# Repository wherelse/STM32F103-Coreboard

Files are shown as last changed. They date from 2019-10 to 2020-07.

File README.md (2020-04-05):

# STM32F103-Coreboard

STM32测试核心板，设计用于硬件程序调试

### 硬件设计
芯片采用STM32F103C8T6，一个1.3inch OLED屏，六个用户按键，一个有源蜂鸣器，使用TP4056充电的1000mah充电电池，TYPE-C充电/数据端口。引出14个GPIO端口和一组SWD调试端口。

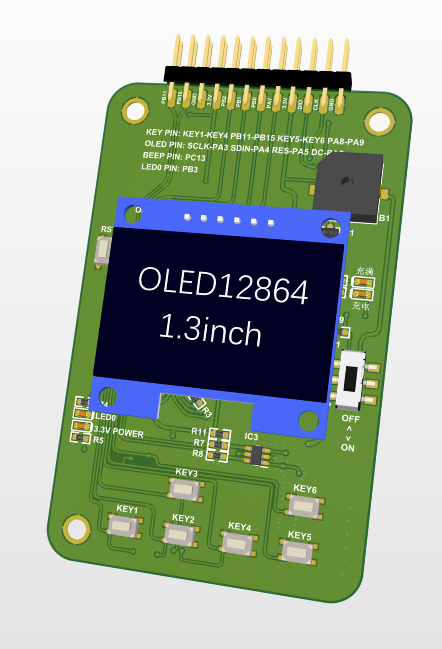
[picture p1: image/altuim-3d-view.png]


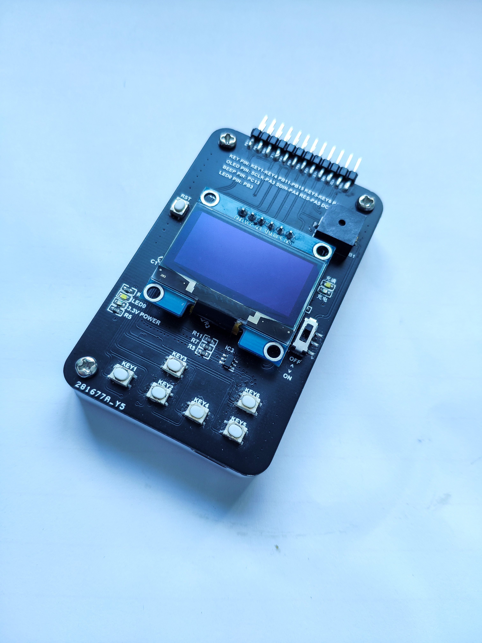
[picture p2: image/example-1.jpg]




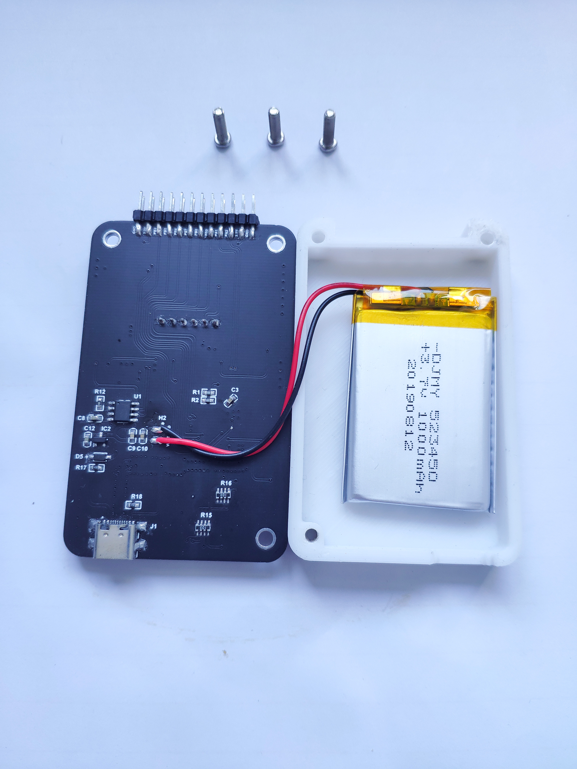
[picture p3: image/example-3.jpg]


PinMap：

| PB11 | PB10 | GND  | 3.3V | PB3  | PB1  | PB0  | PA7  | 3.3V | DIO  | CLK  | GND  |
| :--: | :--: | :--: | :--: | :--: | :--: | :--: | :--: | :--: | :--: | :--: | :--: |
| GND  | 3.3V | PB4  | PB5  | PB6  | PB7  | PB8  | PB9  | PA1  | PA2  | 3.3V | GND  |

TYPE-C端口可程序配置为虚拟串口、USB-HID等，用于数据传输。

使用PA0端口作为内置电池的电压采样输入端口，采样分压为1/2，用于指示电压状态。

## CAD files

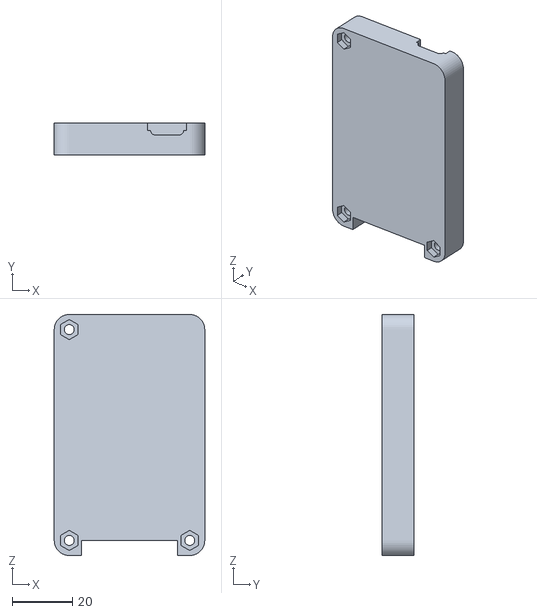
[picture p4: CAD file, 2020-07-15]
hardware/底壳.STL
50.0 x 10.5 x 80.0

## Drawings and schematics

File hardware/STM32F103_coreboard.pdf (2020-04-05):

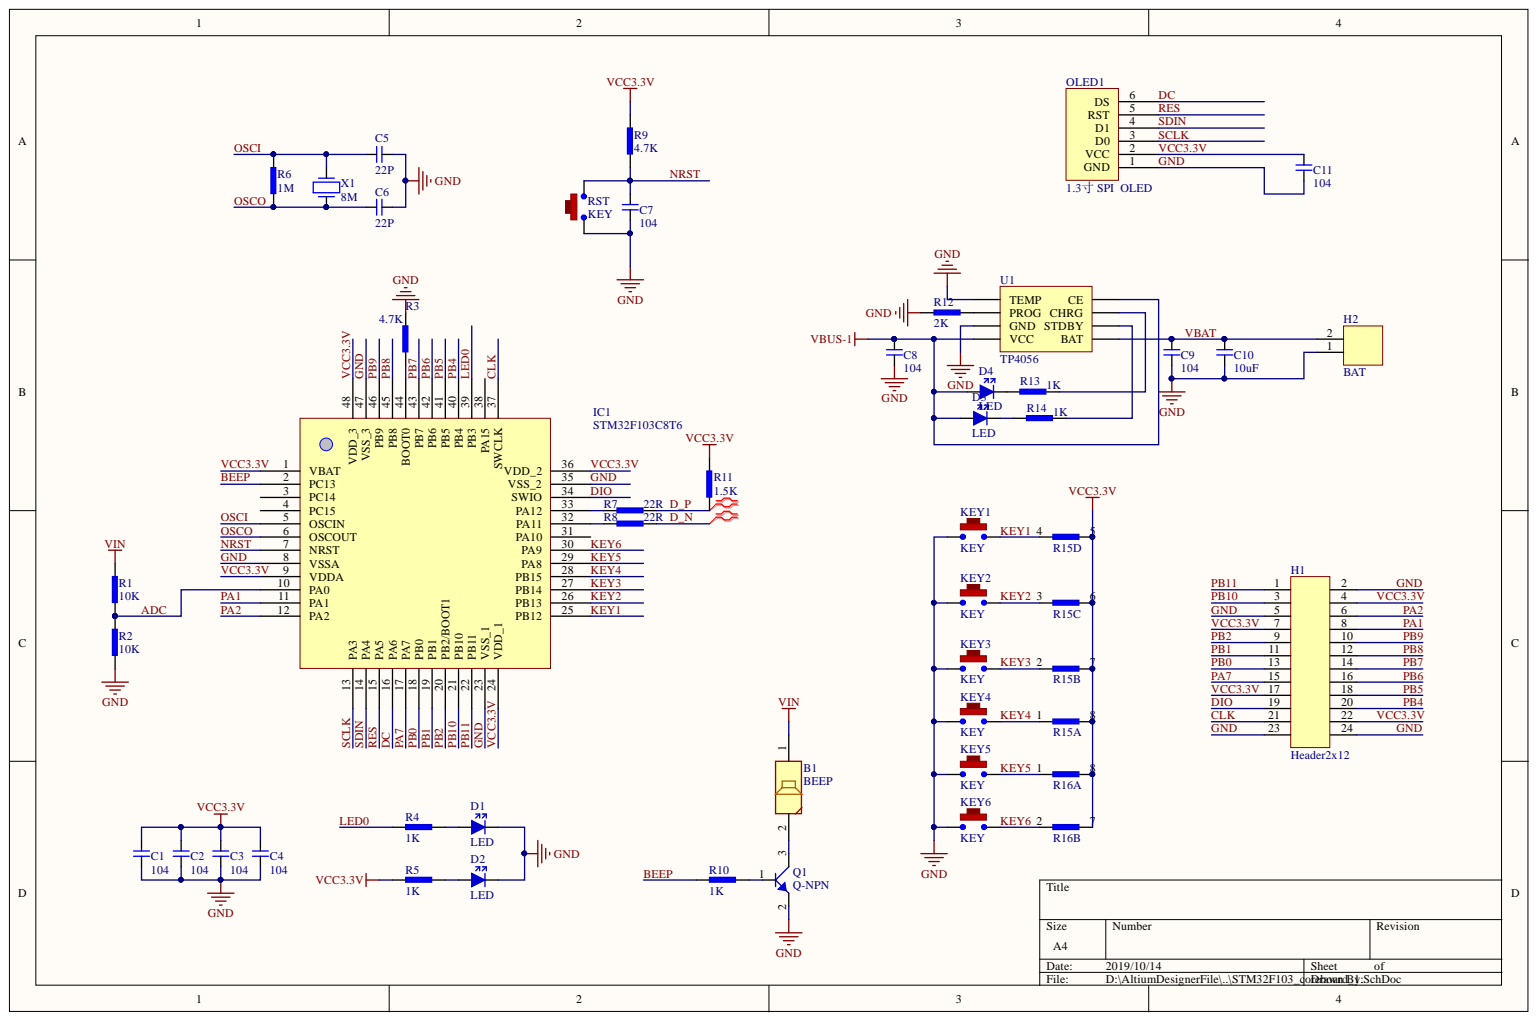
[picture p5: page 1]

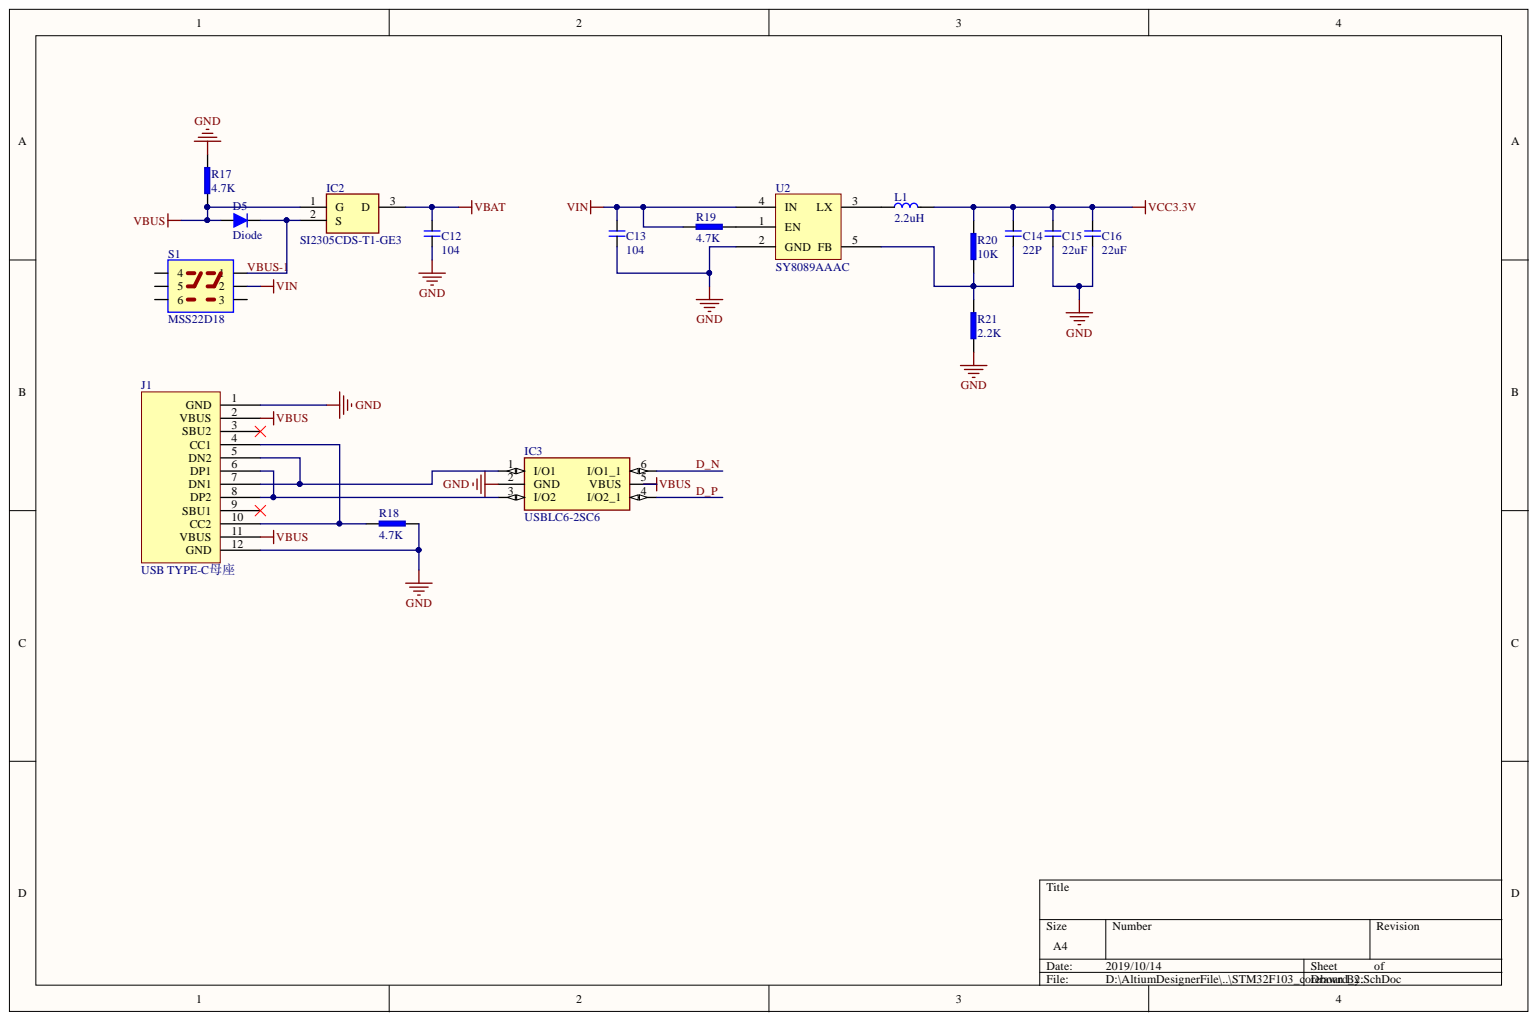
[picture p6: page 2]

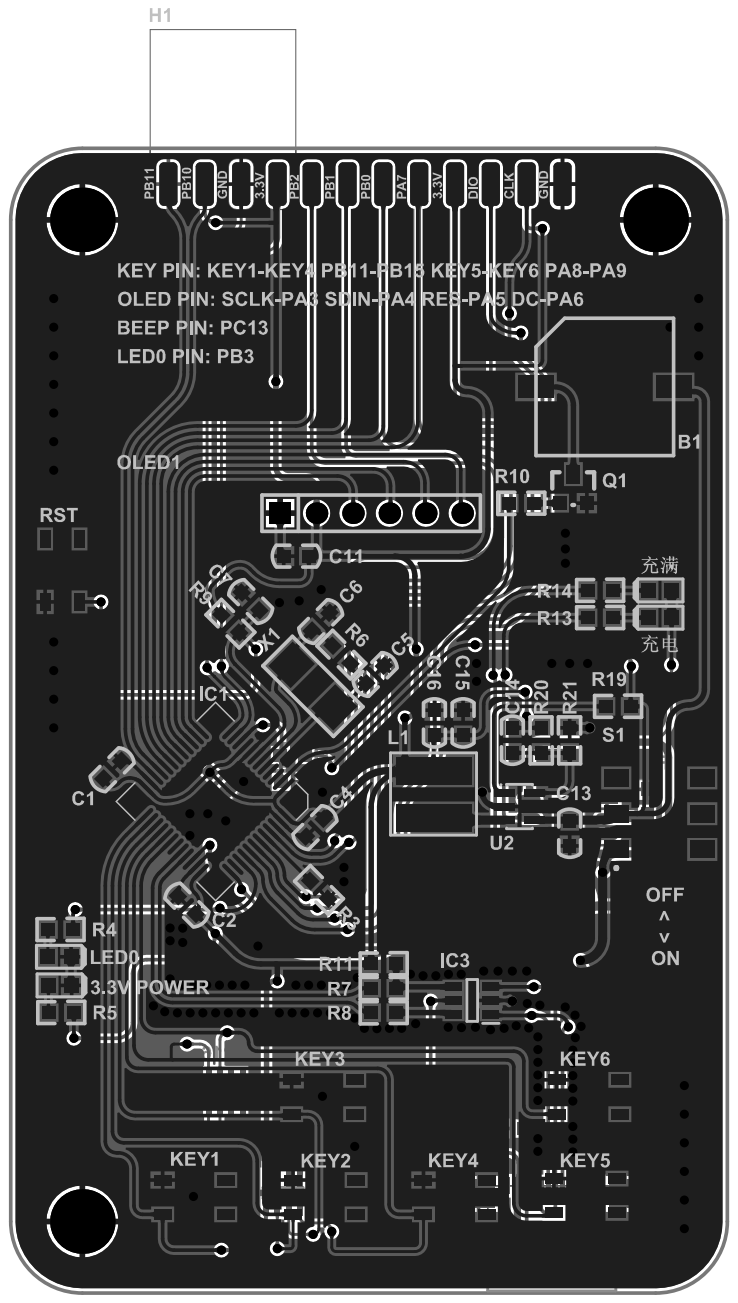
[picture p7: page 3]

Comment | Description | Designator | Footprint | LibRef | Quantity
BEEP | | B1 | MLT-9650 | BEEP | 1
104 | Cap | C1, C2, C3, C4, C7, C8C0603 | | CAP | 10
22P | Cap | C5,C6,C14 | C0603 | CAP | 3
10uF | Cap | C10 | C0603 | CAP | 1
22uF | Cap | C15,C16 | C0603 | CAP | 2
LED | | D1, D2, D3, D4 | LED0603 | LED | 4
Diode | | D5 | SOD123 | Diode | 1
Header2x12 | | H1 | HDR2X12_2.54_180HHeader2x12 | | 1
BAT | | H2 | BATIN | Header1x2 | 1
STM32F103C8T6 | | IC1 | LQFP48 | STM32F103C8T6 | 1
SI2305CDS-T1-GE3 | Integrated Circuit | IC2 | SOT95P237X112-3N | SI2305CDS-T1-GE3 | 1
USBLC6-2SC6 | Integrated Circuit | IC3 | SOT95P280X145-6N | USBLC6-2SC6 | 1
USBTYPE-C母座 | | J1 | USB-TYPEC-SMT | USBTYPE-C | 1
KEY | | KEY1, KEY2, KEY3, KEKEY3 X4X2.5 | | KEY | 7
2.2uH | | L1 | L-CDR5*5 | Inductance | 1
1.3寸 SPI OLED | 1.3寸 SPI OLED 128xOLE D1 | | OLED1.3INCH | 1.3寸 SPI OLED | 1
Q-NPN | | Q1 | SOT-23 | Q-NPN | 1
10K | | R1, R2, R20 | R0603 | RES | 3
4.7K | | R3, R9, R17, R18, R19R0603 | | RES | 5
1K | | R4, R5, R10, R13, R14R0603 | | RES | 5
1M | | R6 | R0603 | RES | 1
22R | | R7,R8 | R0603 | RES | 2
1.5K | | R11 | R0603 | RES | 1
2K | | R12 | R0603 | RES | 1
ResPack-4R | 排阻 | R15,R16 | 8P4R-0603 | ResPack-4R | 2
2.2K | | R21 | R0603 | RES | 1
MSS22D18 | | S1 | SWITCH-MSS22D18 | SWITCH-MSS22D18 | 1
TP4056 | | U1 | SOP8 | TP4056 | 1
SY8089AAAC | | U2 | SOT-23-5 | SY8089AAAC | 1
8M | | X1 | XTAL-5032 | XTAL | 1

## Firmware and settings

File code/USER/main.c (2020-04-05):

#include "includeFile.h"

/*------->定义FLASH相关变量和参数<----------------*/
//要写入到STM32 FLASH的参数数组
float Parameter_Buffer[8] = {0};                  //缓存数组
#define SIZE sizeof(Parameter_Buffer)             //数组长度
#define FLASH_SAVE_ADDR 0X08000000 + (100 * 1024) //STM32F103CBT6 FLASH 空间为128K 将数据存储在100K-128K的区域，\
设置FLASH 保存地址(必须为偶数，且其值要大于本代码所占用FLASH的大小+0X08000000)
float Datatemp[SIZE];
/*------------------------------------------------*/

float voltage = 0;
float lux;
float Apertute[] = {1, 1.2, 1.4, 1.6, 1.8, 2, 2.2, 2.5, 2.8, 3.2, 3.5, 4, 4.5, 5, 5.6, 6.3, 7.1, 8, 9, 10, 11, 13, 14, 16, 18, 20, 22, 32, 45, 64};
float iso[] = {6, 12, 25, 50, 100, 125, 160, 200, 250, 320, 400, 500, 640, 800, 1000, 1250, 1600, 2000, 2500, 3200, 4000, 5000, 6400, 8000, 10000, 12800, 16000, 20000, 25600, 51200};
float exposuretime;
int Apertute_index = 1, iso_index = 4;
float ev;
int tmin, tsec, tfr, tmode;
	
	
void ShutterSpeed_calculate(void);
		
int main(void)
{
  NVIC_PriorityGroupConfig(NVIC_PriorityGroup_2); //设置中断优先级分组为组2：2位抢占优先级，2位响应优先级
  delay_init();                                   //延时函数初始化
  uart_init(115200);                              //串口初始化为115200
  LED_Init();                                     //初始化LED
  Adc_Init();
  KEY_Init();                   //初始化按键
  BEEP_Init();                  //初始化蜂鸣器
  SOLGUI_Hardware_Init();       //OLED初始化
  SOLGUI_Init(&UI_MENU);        //菜单显示框架初始化
  SOLGUI_Refresh();             //OLED刷新
  TIM2_Int_Init(9999, 720 - 1); //100ms中断，屏幕更新，按键读取
  MAX44009_Init();
  USB_Port_Set(1); //USB连接
  Set_USBClock();
  USB_Interrupts_Config();

	USB_Init();
  //	Beeptimes(1);
  while (1)
  {
    voltage = Get_Adc_Average(0, 50) / 4096.0 * 3.45 * 2;
    lux = MAX44009_ReadLux();
    exposuretime = pow(Apertute[Apertute_index], 2) * 64 / (lux * iso[iso_index]);
    ev = log(pow(Apertute[Apertute_index], 2)) / log(2) + log(1 / exposuretime) / log(2);
    ShutterSpeed_calculate();

    usb_printf("lux=%f\n", lux);
    delay_ms(1000);
  }
}
void ShutterSpeed_calculate(void)
{
  if (exposuretime > 60)
  {
    tmin = exposuretime / 60;
    tmode = 2;
  }
  else if (exposuretime < 0.75)
  {
    if (exposuretime < 0.000125)
    {
      tmode = 0;
    }
    else
    {
      tmode = 2;
    }

    if ((exposuretime <= 0.000188) && (exposuretime > 0.000125))
    {
      tfr = 8000;
    }
    if ((exposuretime <= 0.000375) && (exposuretime > 0.000188))
    {
      tfr = 4000;
    }
    if ((exposuretime <= 0.00075) && (exposuretime > 0.000375))
    {
      tfr = 2000;
    }
    if ((exposuretime <= 0.0015) && (exposuretime > 0.00075))
    {
      tfr = 1000;
    }
    if ((exposuretime <= 0.003) && (exposuretime > 0.0015))
    {
      tfr = 500;
    }
    if ((exposuretime <= 0.006) && (exposuretime > 0.003))
    {
      tfr = 250;
    }
    if ((exposuretime <= 0.012333) && (exposuretime > 0.006))
    {
      tfr = 125;
    }
    if ((exposuretime <= 0.025) && (exposuretime > 0.012333))
    {
      tfr = 60;
    }
    if ((exposuretime <= 0.05) && (exposuretime > 0.025))
    {
      tfr = 30;
    }
    if ((exposuretime <= 0.095833) && (exposuretime > 0.05))
    {
      tfr = 15;
    }
    if ((exposuretime <= 0.1875) && (exposuretime > 0.095833))
    {
      tfr = 8;
    }
    if ((exposuretime <= 0.375) && (exposuretime > 0.1875))
    {
      tfr = 4;
    }
    if ((exposuretime <= 0.75) && (exposuretime > 0.375))
    {
      tfr = 2;
    }
  }
  else if ((exposuretime >= 0.75) && (exposuretime < 60))
  {
    tsec = exposuretime; //Exposure in seconds
    tmode = 1;
  }
  if (lux <= 0)
    tmode = 0;
}

//定时器2中断服务函数
void TIM2_IRQHandler(void)
{
  if (TIM_GetITStatus(TIM2, TIM_IT_Update) == SET) //溢出中断
  {
    TIM_ClearITPendingBit(TIM2, TIM_IT_Update); //清除中断标志位
    SOLGUI_InputKey(Key_Scan());
    SOLGUI_Menu_PageStage();
    SOLGUI_Refresh(); //OLED刷新
  }
}

/*
*@菜单内容函数
*/
MENU_PAGE UI_MENU;
__M_PAGE(UI_MENU, "Menu", PAGE_NULL,
         {
           SOLGUI_Cursor(6, 0, 9);
           SOLGUI_Widget_OptionText(0, "BAT:%fV", voltage);
           SOLGUI_Widget_OptionText(1, "luminance:");
           SOLGUI_Widget_OptionText(2, "%flux", lux);
           switch (tmode)
           {
           case 0:
             SOLGUI_Widget_OptionText(3, "overload or no light");
             break;
           case 1:
             SOLGUI_Widget_OptionText(3, "%ds", tsec);
             break;
           case 2:
             SOLGUI_Widget_OptionText(3, "time:1/%d", tfr);
             break;
           }
           SOLGUI_Widget_OptionText(4, "EV:%f", round(ev));
           SOLGUI_Widget_OptionText(5, "ISO:%f", iso[iso_index]);
           SOLGUI_Widget_OptionText(6, "F%f", Apertute[Apertute_index]);
           SOLGUI_Widget_Spin(7, "isonum:", INT8, 0, 30, &iso_index);
           SOLGUI_Widget_Spin(8, "Anum:", INT8, 0, 30, &Apertute_index);
           //			 SOLGUI_Widget_Spin(1, "ModeSelect:", INT8, 0, 1, &ControlMode_Flag);
           //			 SOLGUI_Widget_GotoPage(2, &DATA_EDIT);
           //			 SOLGUI_Widget_GotoPage(3, &CAN_IO);
         });
void FlashSaveData(void)
{
  //	Parameter_Buffer[0] = speed.kp;
  //	Parameter_Buffer[1] = speed.ki;
  //	Parameter_Buffer[2] = SetSpeed;
  //	Parameter_Buffer[3] = current.kp;
  //	Parameter_Buffer[4] = current.ki;
  //	Parameter_Buffer[5] = SetCurrent;
  //	Parameter_Buffer[6] = EncoderPulse;
  //	//STMFLASH_Write(FLASH_SAVE_ADDR, (u16 *)Parameter_Buffer, SIZE);
  //	FlashSaveFlag = 1;
}

void FlashInitData(void)
{
  //	//STMFLASH_Read(FLASH_SAVE_ADDR, (u16 *)Datatemp, SIZE);
  //	speed.kp = Datatemp[0];
  //	speed.ki = Datatemp[1];
  //	SetSpeed = Datatemp[2];
  //	current.kp = Datatemp[3];
  //	current.ki = Datatemp[4];
  //	SetCurrent = Datatemp[5];
  //	EncoderPulse = Datatemp[6];
}

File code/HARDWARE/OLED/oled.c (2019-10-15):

//////////////////////////////////////////////////////////////////////////////////
//本程序只供学习使用，未经作者许可，不得用于其它任何用途
//中景园电子
//店铺地址：http://shop73023976.taobao.com/?spm=2013.1.0.0.M4PqC2
//
//  文 件 名   : main.c
//  版 本 号   : v2.0
//  作    者   : HuangKai
//  生成日期   : 2014-0101
//  最近修改   :
//  功能描述   : OLED 4接口演示例程(51系列)
//              说明:
//              ----------------------------------------------------------------
//              GND    电源地
//              VCC  接5V或3.3v电源
//              D0   接PA5（SCL）
//              D1   接PA7（SDA）
//              RES  接PB0
//              DC   接PB1
//              CS   接PA4
//              ----------------------------------------------------------------
// 修改历史   :
// 日    期   :
// 作    者   : HuangKai
// 修改内容   : 创建文件
//版权所有，盗版必究。
//Copyright(C) 中景园电子2014/3/16
//All rights reserved
//******************************************************************************/

#include "oled.h"
#include "stdlib.h"
#include "oledfont.h"
#include "delay.h"
//OLED的显存
//存放格式如下.
//[0]0 1 2 3 ... 127
//[1]0 1 2 3 ... 127
//[2]0 1 2 3 ... 127
//[3]0 1 2 3 ... 127
//[4]0 1 2 3 ... 127
//[5]0 1 2 3 ... 127
//[6]0 1 2 3 ... 127
//[7]0 1 2 3 ... 127

#if OLED_MODE == 1
//向SSD1106写入一个字节。
//dat:要写入的数据/命令
//cmd:数据/命令标志 0,表示命令;1,表示数据;
void OLED_WR_Byte(u8 dat, u8 cmd)
{
	DATAOUT(dat);
	if (cmd)
		OLED_DC_Set();
	else
		OLED_DC_Clr();
	OLED_CS_Clr();
	OLED_WR_Clr();
	OLED_WR_Set();
	OLED_CS_Set();
	OLED_DC_Set();
}
#else
//向SSD1106写入一个字节。
//dat:要写入的数据/命令
//cmd:数据/命令标志 0,表示命令;1,表示数据;
void OLED_WR_Byte(u8 dat, u8 cmd)
{
	u8 i;
	if (cmd)
		OLED_DC_Set();
	else
		OLED_DC_Clr();
	//OLED_CS_Clr();
	for (i = 0; i < 8; i++)
	{
		OLED_SCLK_Clr();
		if (dat & 0x80)
			OLED_SDIN_Set();
		else
			OLED_SDIN_Clr();
		OLED_SCLK_Set();
		dat <<= 1;
	}
	//OLED_CS_Set();
	OLED_DC_Set();
}
#endif
void OLED_Set_Pos(unsigned char x, unsigned char y)
{
	OLED_WR_Byte(0xb0 + y, OLED_CMD);
	OLED_WR_Byte((((x + 2) & 0xf0) >> 4) | 0x10, OLED_CMD);
	OLED_WR_Byte(((x + 2) & 0x0f), OLED_CMD);
}
//开启OLED显示
void OLED_Display_On(void)
{
	OLED_WR_Byte(0X8D, OLED_CMD); //SET DCDC命令
	OLED_WR_Byte(0X14, OLED_CMD); //DCDC ON
	OLED_WR_Byte(0XAF, OLED_CMD); //DISPLAY ON
}
//关闭OLED显示
void OLED_Display_Off(void)
{
	OLED_WR_Byte(0X8D, OLED_CMD); //SET DCDC命令
	OLED_WR_Byte(0X10, OLED_CMD); //DCDC OFF
	OLED_WR_Byte(0XAE, OLED_CMD); //DISPLAY OFF
}
//清屏函数,清完屏,整个屏幕是黑色的!和没点亮一样!!!
void OLED_Clear(void)
{
	u8 i, n;
	for (i = 0; i < 8; i++)
	{
		OLED_WR_Byte(0xb0 + i, OLED_CMD); //设置页地址（0~7）
		OLED_WR_Byte(0x02, OLED_CMD);	 //设置显示位置—列低地址
		OLED_WR_Byte(0x10, OLED_CMD);	 //设置显示位置—列高地址
		for (n = 0; n < 128; n++)
			OLED_WR_Byte(0, OLED_DATA);
	} //更新显示
}

//在指定位置显示一个字符,包括部分字符
//x:0~127
//y:0~63
//mode:0,反白显示;1,正常显示
//size:选择字体 16/12
void OLED_ShowChar(u8 x, u8 y, u8 chr, uint8_t size)
{
	unsigned char c = 0, i = 0;
	c = chr - ' '; //得到偏移后的值
	if (x > Max_Column - 1)
	{
		x = 0;
		y = y + 2;
	}
	if (size == 16)
	{
		OLED_Set_Pos(x, y);
		for (i = 0; i < 8; i++)
			OLED_WR_Byte(F8X16[c * 16 + i], OLED_DATA);
		OLED_Set_Pos(x, y + 1);
		for (i = 0; i < 8; i++)
			OLED_WR_Byte(F8X16[c * 16 + i + 8], OLED_DATA);
	}
	else if (size == 8)
	{
		OLED_Set_Pos(x, y);
		for (i = 0; i < 6; i++)
			OLED_WR_Byte(F6x8[c][i], OLED_DATA);
	}
	else if (size==32)
	{
		OLED_Set_Pos(x, y);
		for (i = 0; i < 16; i++)
			OLED_WR_Byte(F16x32[c][i], OLED_DATA);
		OLED_Set_Pos(x, y + 1);
		for (i = 0; i < 16; i++)
			OLED_WR_Byte(F16x32[c][i + 16], OLED_DATA);
		OLED_Set_Pos(x, y + 2);
		for (i = 0; i < 16; i++)
			OLED_WR_Byte(F16x32[c][i + 32], OLED_DATA);
		OLED_Set_Pos(x, y + 3);
		for (i = 0; i < 16; i++)
			OLED_WR_Byte(F16x32[c][i + 48], OLED_DATA);
	}
	
}
//m^n函数
u32 oled_pow(u8 m, u8 n)
{
	u32 result = 1;
	while (n--)
		result *= m;
	return result;
}
//显示2个数字
//x,y :起点坐标
//len :数字的位数
//size:字体大小
//mode:模式	0,填充模式;1,叠加模式
//num:数值(0~4294967295);
void OLED_ShowNum(u8 x, u8 y, u32 num, u8 len, u8 size)
{
	u8 t, temp;
	u8 enshow = 0;
	if(size==16)
	{
	for (t = 0; t < len; t++)
	{
		temp = (num / oled_pow(10, len - t - 1)) % 10;
		if (enshow == 0 && t < (len - 1))
		{
			if (temp == 0)
			{
				OLED_ShowChar(x + (size / 2) * t, y, ' ', size);
				continue;
			}
			else
				enshow = 1;
		}
		OLED_ShowChar(x + (size / 2) * t, y, temp + '0', size);
	}
	}
	else if(size==8)
	{
		for (t = 0; t < len; t++)
		{
			temp = (num / oled_pow(10, len - t - 1)) % 10;
			if (enshow == 0 && t < (len - 1))
			{
				if (temp == 0)
				{
					OLED_ShowChar(x + 6 * t, y, ' ', size);
					continue;
				}
				else
					enshow = 1;
			}
			OLED_ShowChar(x + 6 * t, y, temp + '0', size);
		}
	}
	else if (size == 32)
	{
		for (t = 0; t < len; t++)
		{
			temp = (num / oled_pow(10, len - t - 1)) % 10;
			if (enshow == 0 && t < (len - 1))
			{
				if (temp == 0)
				{
					OLED_ShowChar(x + 16 * t, y, ' ', size);
					continue;
				}
				else
					enshow = 1;
			}
			OLED_ShowChar(x + 16 * t, y, temp + '0', size);
		}
	}
}

//显示浮点数
void OLED_ShowFloatNum(u8 x, u8 y, float num, u8 len, u8 size)
{
	u8 t, temp;
	u8 enshow = 0;
	u16 num1;
	num1 = num * 100;
	if (size == 16)
	{
		for (t = 0; t < len; t++)
		{
			temp = (num1 / oled_pow(10, len - t - 1)) % 10;
			if (t == (len - 2))
			{
				OLED_ShowChar(x + 8 * (len - 2), y, '.', size);
				t++;
				len += 1;
			}
			OLED_ShowChar(x + 8 * t, y, temp + 48, size);
		}
	}
	else if (size == 8)
	{
		for (t = 0; t < len; t++)
		{
			temp = (num1 / oled_pow(10, len - t - 1)) % 10;
			if (t == (len - 2))
			{
				OLED_ShowChar(x + 6 * (len - 2), y, '.', size);
				t++;
				len += 1;
			}
			OLED_ShowChar(x + 6 * t, y, temp + 48, size);
		}
	}
	else if (size == 32)
	{
		for (t = 0; t < len; t++)
		{
			temp = (num1 / oled_pow(10, len - t - 1)) % 10;
			if (t == (len - 2))
			{
				OLED_ShowChar(x + 16 * (len - 2), y, '.', size);
				t++;
				len += 1;
			}
			OLED_ShowChar(x + 16 * t, y, temp + 48, size);
		}
	}
}

//显示一个字符号串
void OLED_ShowString(u8 x, u8 y, u8 *chr, uint8_t size)
{
	unsigned char j = 0;
	if (size == 16)
	{
		while (chr[j] != '\0')
		{
			OLED_ShowChar(x, y, chr[j], size);
			x += 8;
			if (x > 120)
			{
				x = 0;
				y += 2;
			}
			j++;
		}
	}
	else if (size == 8)
	{
		while (chr[j] != '\0')
		{
			OLED_ShowChar(x, y, chr[j], size);
			x += 6;
			if (x > 122)
			{
				x = 0;
				y += 1;
			}
			j++;
		}
	}
	else if (size == 32)
	{
		while (chr[j] != '\0')
		{
			OLED_ShowChar(x, y, chr[j], size);
			x += 16;
			if (x > 111)
			{
				x = 0;
				y += 1;
			}
			j++;
		}
	}
}
//显示汉字
void OLED_ShowCHinese(u8 x, u8 y, u8 no)
{
	u8 t, adder = 0;
	OLED_Set_Pos(x, y);
	for (t = 0; t < 16; t++)
	{
		OLED_WR_Byte(Hzk[2 * no][t], OLED_DATA);
		adder += 1;
	}
	OLED_Set_Pos(x, y + 1);
	for (t = 0; t < 16; t++)
	{
		OLED_WR_Byte(Hzk[2 * no + 1][t], OLED_DATA);
		adder += 1;
	}
}
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

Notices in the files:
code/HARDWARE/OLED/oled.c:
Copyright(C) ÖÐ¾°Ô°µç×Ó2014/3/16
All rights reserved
